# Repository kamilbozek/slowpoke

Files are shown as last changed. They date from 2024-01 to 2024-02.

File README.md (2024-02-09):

# Slowpoke (ヤドン)
Slowpoke (ヤドン) is a 34-key split keyboard.

Features:
* choc spacing
* Pro Micro compatible
* supports Kailh hotswap sockets
* reversible PCB

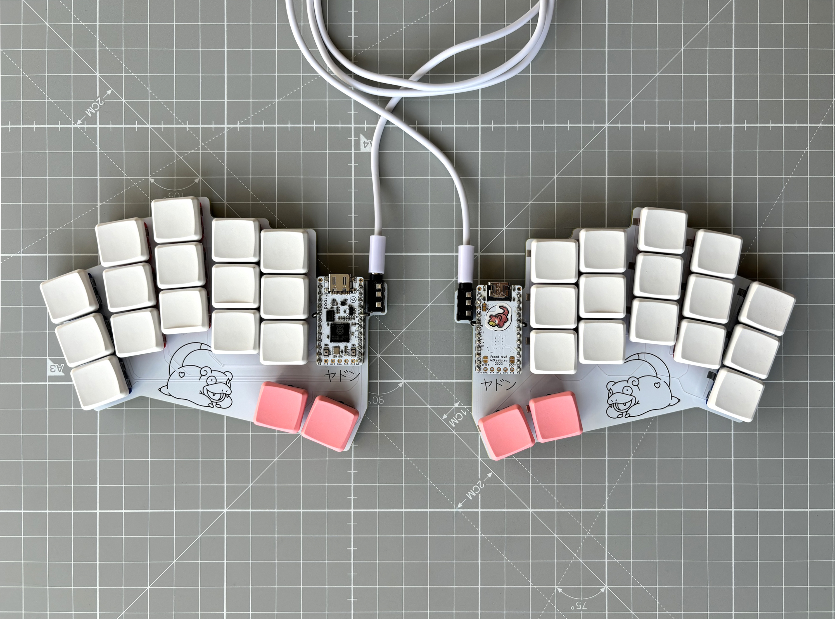
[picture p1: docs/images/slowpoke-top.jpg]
Slowpoke - top view

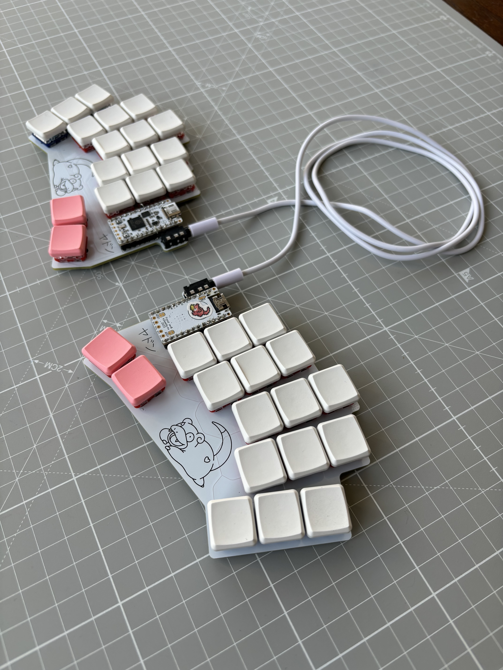
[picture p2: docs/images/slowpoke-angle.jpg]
Slowpoke - angle view

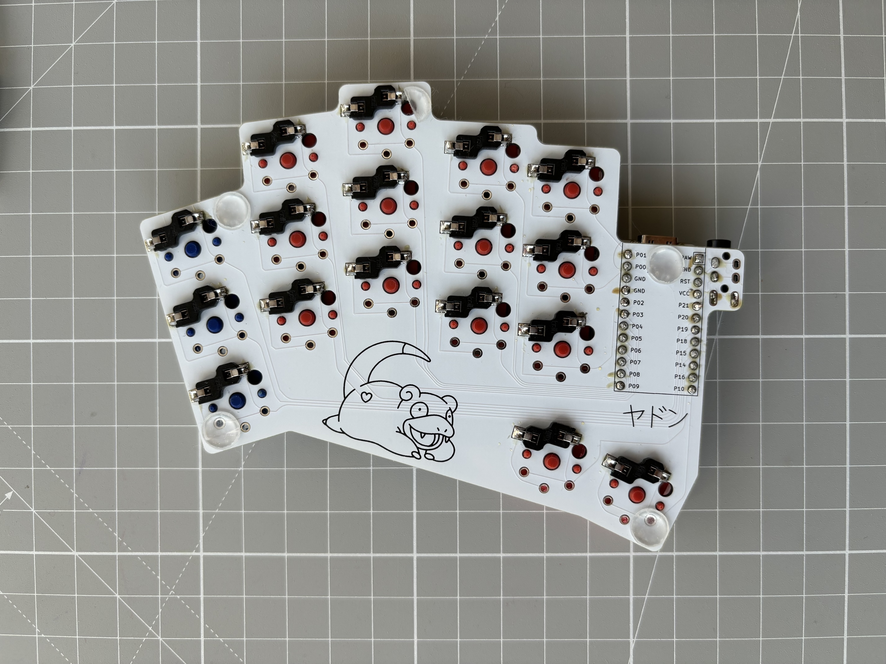
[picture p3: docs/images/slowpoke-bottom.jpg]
Slowpoke - bottom view


## Thanks
* [@tapioki](https://github.com/tapioki) for [Architeuthis dux](https://github.com/tapioki/cephalopoda/tree/main/Architeuthis%20dux) which heavily inspired this keyboard
* FlatFootFox for [a great series of articles about designing a keyboard with Ergogen and KiCad](https://flatfootfox.com/ergogen-introduction/)

## Changelog
### 0.1.0
The initial version of the keyboard.

This version has a routing bug that requires switching pins `P02` and `P21` so that the TRRS socket is routed to the `P02` and the inner column is routed to `P21`.

See [how to fix routing](docs/routing-fix.md).

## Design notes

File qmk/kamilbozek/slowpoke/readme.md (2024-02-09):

# kamilbozek/slowpoke

Slowpoke (ヤドン) is a 34-key split keyboard.

* Keyboard Maintainer: [Kamil Bozek](https://github.com/kamilbozek)
* Hardware Supported: Pro Micro

Build the QMK firmware (after setting up your build environment):

    make kamilbozek/slowpoke:default

Flashing the keyboard:

    make kamilbozek/slowpoke:default:flash

See the [build environment setup](https://docs.qmk.fm/#/getting_started_build_tools) and the [make instructions](https://docs.qmk.fm/#/getting_started_make_guide) for more information. Brand new to QMK? Start with our [Complete Newbs Guide](https://docs.qmk.fm/#/newbs).

## Bootloader

Enter the bootloader in 3 ways:

* **Bootmagic reset**: Hold down the key at (0,0) in the matrix (usually the top left key or Escape) and plug in the keyboard
* **Physical reset button**: Briefly press the button on the back of the PCB - some may have pads you must short instead
* **Keycode in layout**: Press the key mapped to `QK_BOOT` if it is available

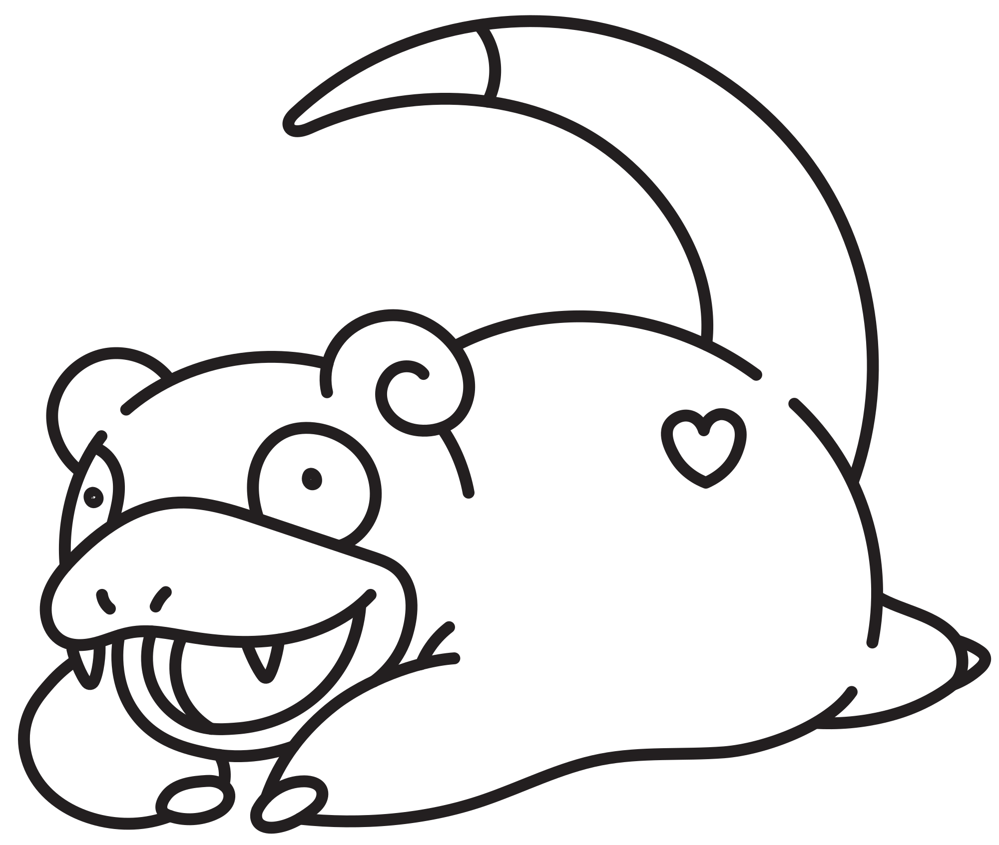
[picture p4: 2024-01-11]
graphics/slowpoke-02-mirror.png

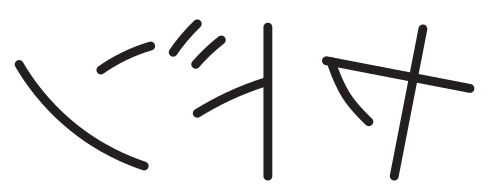
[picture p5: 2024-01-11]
graphics/slowpoke-03-mirror.png

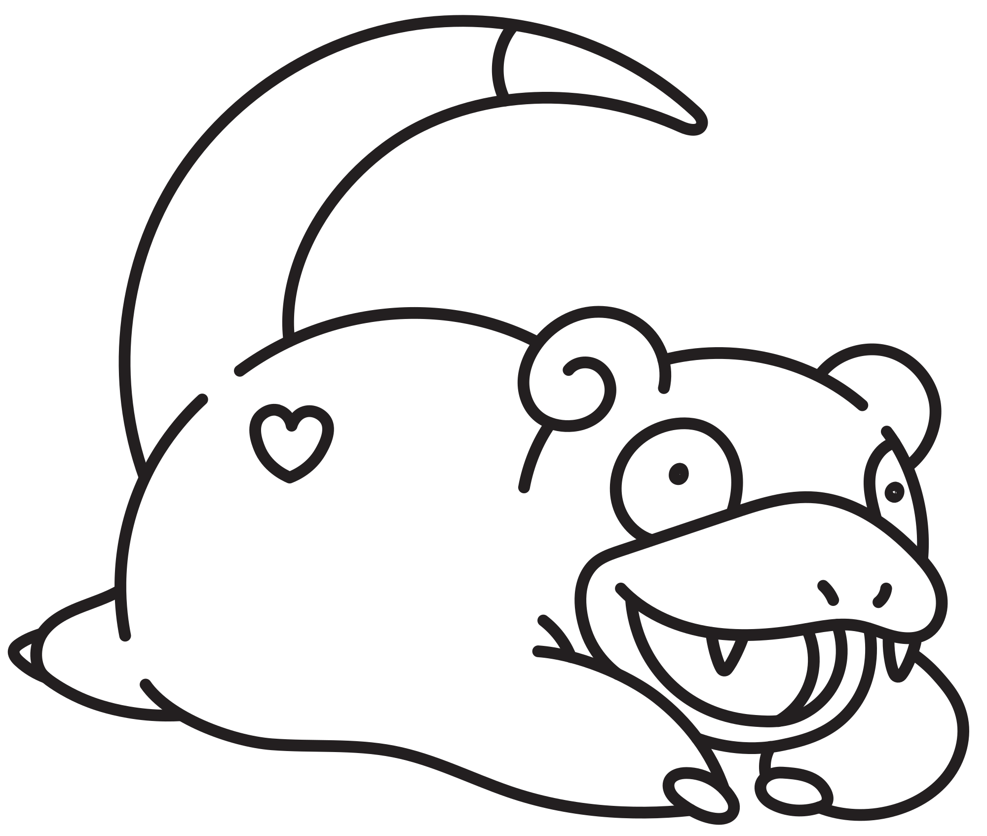
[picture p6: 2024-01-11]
graphics/slowpoke-02.png

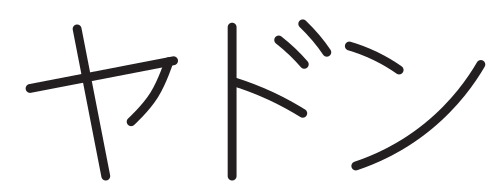
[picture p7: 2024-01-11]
graphics/slowpoke-03.png

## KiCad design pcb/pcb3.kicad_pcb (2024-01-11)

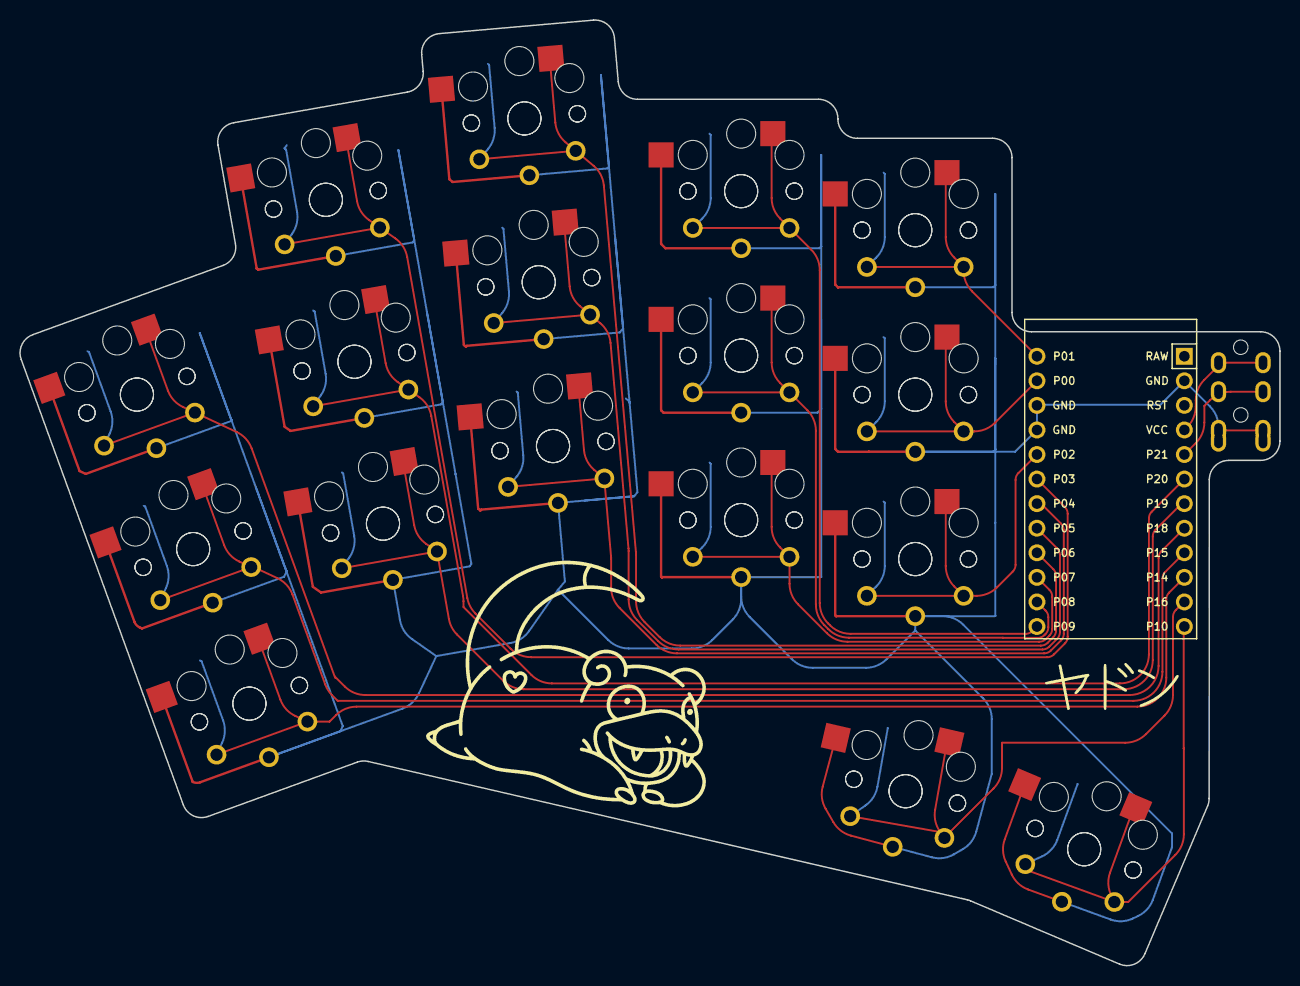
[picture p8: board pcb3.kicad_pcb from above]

Board: 2 copper layers, 130.2 x 97.8 mm, 36 parts (0 on the bottom side), 20 nets.

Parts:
MCU1: ProMicro
S1, S2, S3, S4, S5, S6, S7, S8, S9, S10, S11, S12, S13, S14, S15, S16, S17, S18, S19, S20, S21, S22, S23, S24, S25, S26, S27, S28, S29, S30, S31, S32, S33, S34: PG1350
TRRS1: TRRS-PJ-320A-dual

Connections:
GND: MCU1.2, MCU1.15, MCU1.16, S1.2, S2.2, S3.2, S4.2, S5.2, S6.2, S7.2, S8.2, S9.2, S10.2, S11.2, S12.2, S13.2, S14.2, S15.2, S16.2, S17.2, S18.2, S19.2, S20.2, S21.2, S22.2, S23.2, S24.2, S25.2, S26.2, S27.2, S28.2, S29.2, S30.2, S31.2, S32.2, S33.2, S34.2, TRRS1.1, TRRS1.2
P0: MCU1.14, S14.1, S31.1
P1: MCU1.13, S15.1, S32.1
P2: MCU1.17, S13.1, S30.1
P3: MCU1.18, S6.1, S23.1
P4: MCU1.19, S7.1, S24.1
P5: MCU1.20, S8.1, S25.1
P6: MCU1.21, S9.1, S26.1
P7: MCU1.22, S10.1, S27.1
P8: MCU1.23, S11.1, S28.1
P9: MCU1.24, S12.1, S29.1
P10: MCU1.12, S17.1, S34.1
P14: MCU1.10, S1.1, S18.1
P15: MCU1.9, S2.1, S19.1
P16: MCU1.11, S16.1, S33.1
P18: MCU1.8, S3.1, S20.1
P19: MCU1.7, S4.1, S21.1
P20: MCU1.6, S5.1, S22.1
P21: MCU1.5, TRRS1.3
VCC: MCU1.4, TRRS1.4

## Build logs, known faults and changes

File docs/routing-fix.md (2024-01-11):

# Fixing routing bug in v0.1.0
The goal is to connect MCU's pin `P21` with socket marked with `P02` on the PCB and MCU's pin `P02` with `P21` on the PCB. 

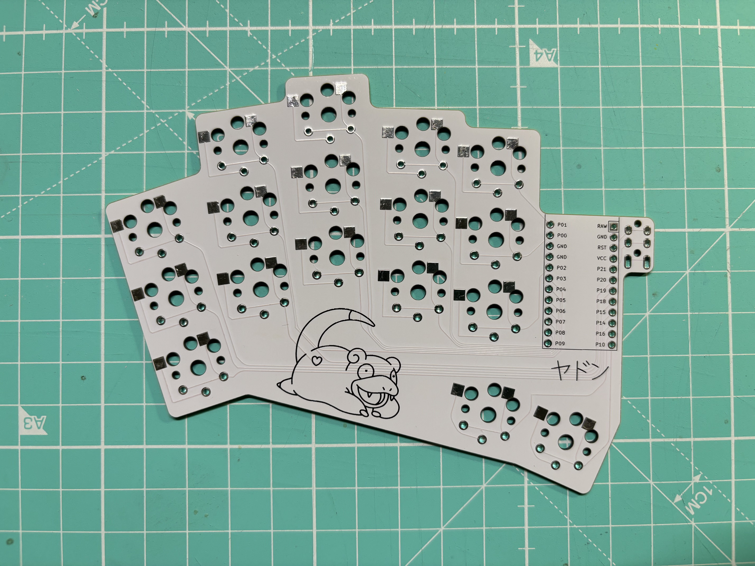
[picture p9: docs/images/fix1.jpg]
Slowpoke - PCB


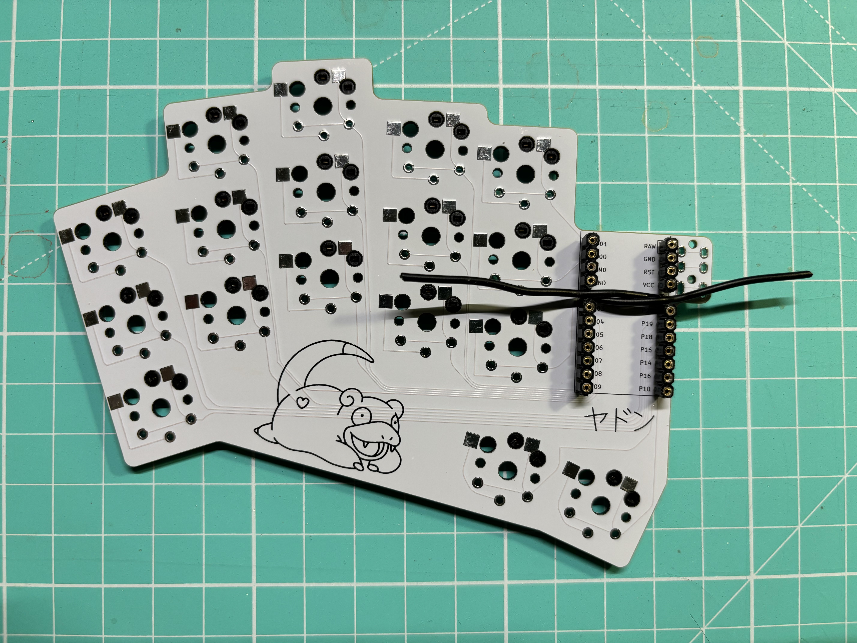
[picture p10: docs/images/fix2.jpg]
Slowpoke - wiring


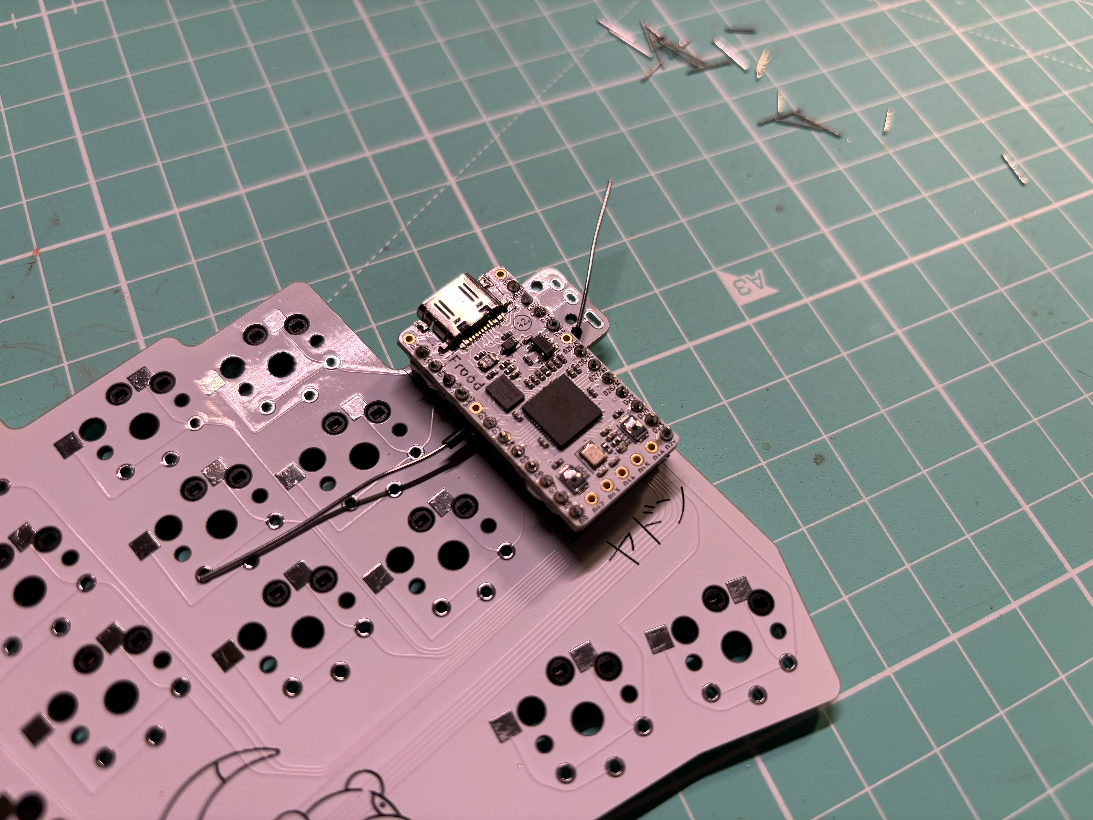
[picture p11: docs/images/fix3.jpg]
Slowpoke - mounted MCU


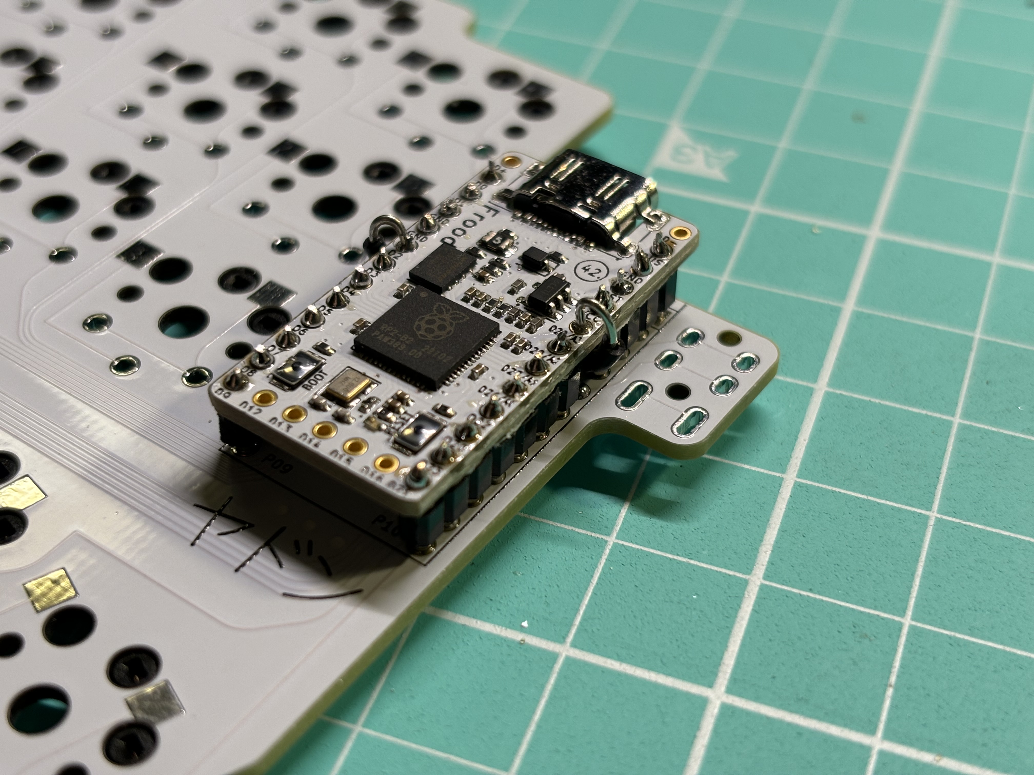
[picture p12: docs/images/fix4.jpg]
Slowpoke - soldered
